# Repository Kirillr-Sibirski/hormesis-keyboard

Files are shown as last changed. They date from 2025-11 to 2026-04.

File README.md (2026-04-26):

# Hormesis Keyboard

A custom low-profile wireless split mechanical keyboard, inspired by the Corne v3.

---

## Overview

| Spec | Detail |
|---|---|
| Keys | 50 (split 25/25) |
| Layout | 5×6 column stagger per half + 3-key thumb cluster |
| Profile | Low-profile |
| Wireless | Bluetooth 5.0, up to 5 device profiles |
| Controller | nice!nano v2 (nRF52840) |
| RGB | WS2812 underglow, 25 LEDs per half |

---

## Repository Structure

```
hardware/
├── kicad/          KiCAD PCB schematic and layout
├── footprints/     Ergogen custom footprints
├── output/         Generated outputs (gerbers, outlines, cases)
├── top_plate/      Top plate Ergogen design
├── firmware/       Pre-built .uf2 files ready to flash
└── config.yaml     Ergogen PCB config

boards/             ZMK shield definition (hormesis_left / hormesis_right)
config/             ZMK keymap and firmware config
zephyr/             ZMK module config
build.yaml          ZMK GitHub Actions build targets
.github/workflows/  Auto-build firmware on push
```

---

## Layout

```
  1   2   3   4   5                   6   7   8   9   0
TAB   Q   W   E   R   T       Y   U   I   O   P  ESC
CAP   A   S   D   F   G       H   J   K   L   ;  SFT
  Z   X   C   V   B                   N   M   ,   .   /
                CTL ALT GUI     SPC  FN BSP
```

### Fn Layer (hold FN)

```
 F1  F2  F3  F4  F5                  F6  F7  F8  F9 F10
  `   !   @   #   $   %       ^   &   *   (   )  DEL
  _   _   -   =   [   ]      LFT DWN  UP RGT   '  ENT
BTC BT0 BT1 BT2 BT3             BT4 RGB  H+  S+   \
            USB BLE TOG     BRI EFF BOT
```

`BTC` = clear BT, `BT0–4` = select profile, `RGB` = toggle underglow, `H+/S+` = hue/saturation, `BRI` = brightness, `EFF` = next effect, `BOT` = bootloader, `USB/BLE/TOG` = output source.

---

## Flashing Firmware

Pre-built `.uf2` files are in `hardware/firmware/`:

```
hardware/firmware/hormesis_left-nice_nano_v2.uf2
hardware/firmware/hormesis_right-nice_nano_v2.uf2
```

1. Double-tap the reset button on the nice!nano — it mounts as a USB drive (`NICENANO`).
2. Drag the matching `.uf2` file onto the drive.
3. Flash left first, then right.

---

## Customizing Keymaps

**Edit the keymap** in `config/hormesis.keymap`, push to GitHub, and the Actions workflow auto-builds new firmware. Download from the Actions tab.

**ZMK Studio (GUI, no recompile):** Add `CONFIG_ZMK_STUDIO=y` to `config/hormesis.conf`, rebuild, flash, then use [zmk.studio](https://zmk.studio) to remap keys live over USB or BLE.

---

## Bill of Materials

| Part | Qty |
|---|-----|
| nice!nano v2 | 2 |
| Low-profile MX switches | 50 |
| Low-profile keycaps | 50 |
| WS2812B LEDs | 50 (25 per half) |
| SOD-123 diodes | 50 |
| JST PH 2.0 battery connector | 2 |
| LiPo battery (301230 or similar) | 2 |
| Reset switch (3×6mm SPST) | 2 |

---

## PCB Fabrication

Gerbers are in `hardware/kicad/gerber/`. Recommended fab settings:

- Layers: 2
- Thickness: 1.6 mm
- Surface finish: HASL or ENIG
- Quantity: 5 (gives 2 full keyboards + spares)

---

## License

MIT

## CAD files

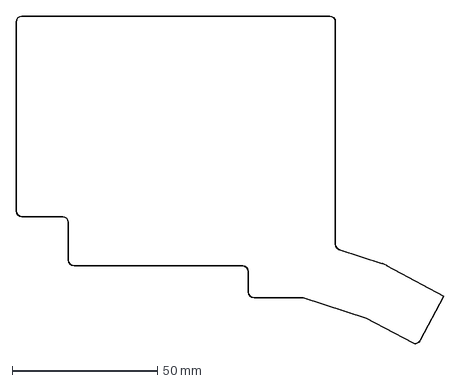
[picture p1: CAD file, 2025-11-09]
hardware/output/outlines/main.dxf
147.4 x 112.8 mm

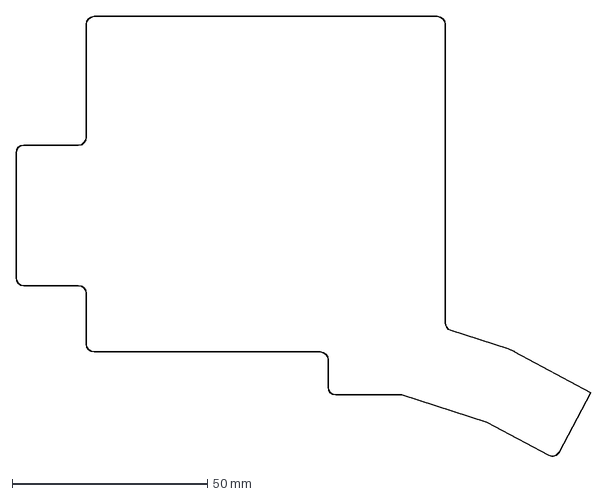
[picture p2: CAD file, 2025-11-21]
hardware/top_plate/output/outlines/main.dxf
147.4 x 112.8 mm

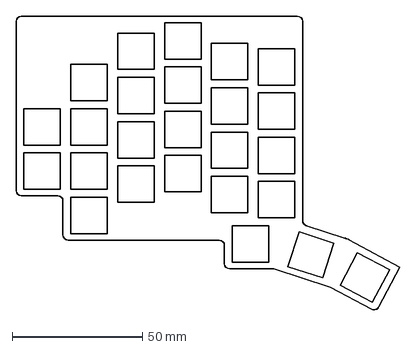
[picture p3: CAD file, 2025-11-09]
hardware/output/outlines/leftcutout.dxf
147.4 x 112.8 mm

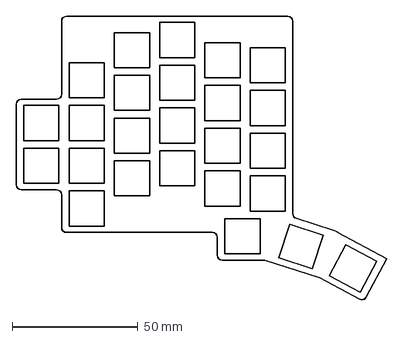
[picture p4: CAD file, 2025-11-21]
hardware/top_plate/output/outlines/leftcutout.dxf
147.4 x 112.8 mm

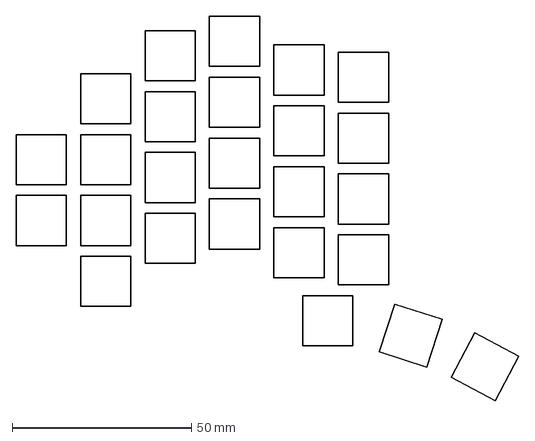
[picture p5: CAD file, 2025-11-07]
hardware/output/outlines/leftkeys.dxf
140.4 x 107.3 mm

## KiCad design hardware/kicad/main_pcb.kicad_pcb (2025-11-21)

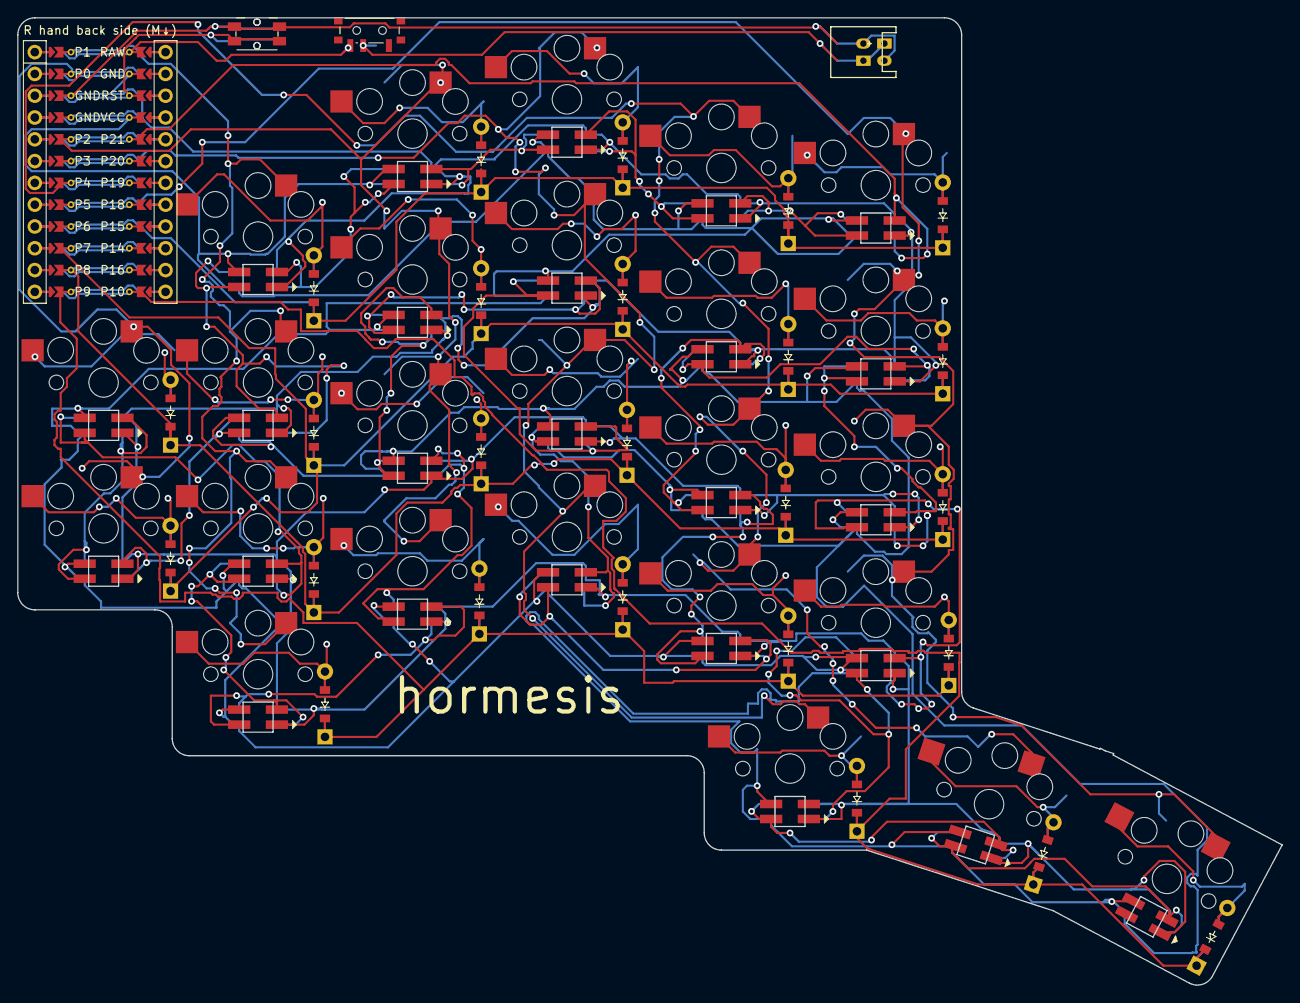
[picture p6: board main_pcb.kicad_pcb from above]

Board: 2 copper layers, 147.4 x 112.7 mm, 81 parts (0 on the bottom side), 66 nets.

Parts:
B1, B2: Panasonic_EVQPUL_EVQPUC
D1, D2, D3, D4, D5, D6, D7, D8, D9, D10, D11, D12, D13, D14, D15, D16, D17, D18, D19, D20, D21, D22, D23, D24, D25: ComboDiode
JST1, JST2: JST_PH_S2B-PH-K_02x2.00mm_Angled
LED1, LED2, LED3, LED4, LED5, LED6, LED7, LED8, LED9, LED10, LED11, LED12, LED13, LED14, LED15, LED16, LED17, LED18, LED19, LED20, LED21, LED22, LED23, LED24, LED25: WS2812B
MCU1: mcu_supermini_nrf52840
S1, S2, S3, S4, S5, S6, S7, S8, S9, S10, S11, S12, S13, S14, S15, S16, S17, S18, S19, S20, S21, S22, S23, S24, S25: PG1350
SW1: power_switch

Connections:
GND: B1.1, B2.1, JST1.2, JST2.2, LED1.3, LED2.3, LED3.3, LED4.3, LED5.3, LED6.3, LED7.3, LED8.3, LED9.3, LED10.3, LED11.3, LED12.3, LED13.3, LED14.3, LED15.3, LED16.3, LED17.3, LED18.3, LED19.3, LED20.3, LED21.3, LED22.3, LED23.3, LED24.3, LED25.3, MCU1.102, MCU1.121, MCU1.122
P0: MCU1.123, S21.1, S22.1
P1: MCU1.124, S1.1, S2.1, S3.1, S4.1
P2: MCU1.120, S5.1, S6.1, S7.1, S8.1
P3: MCU1.119, S9.1, S10.1, S11.1, S12.1, S23.1
P4: MCU1.118, S13.1, S14.1, S15.1, S16.1, S24.1
P5: MCU1.117, S17.1, S18.1, S19.1, S20.1, S25.1
P6: D4.1, D8.1, D12.1, D16.1, D20.1, MCU1.116
P7: D3.1, D7.1, D11.1, D15.1, D19.1, D21.1, MCU1.115
P8: D2.1, D6.1, D10.1, D14.1, D18.1, D22.1, MCU1.114
P9: D1.1, D5.1, D9.1, D13.1, D17.1, MCU1.113
P10: D23.1, D24.1, D25.1, MCU1.112
P21: LED20.4, MCU1.105
RAW: MCU1.101, SW1.3, SW1.6
RST: B1.2, B2.2, MCU1.103
VCC: LED1.1, LED2.1, LED3.1, LED4.1, LED5.1, LED6.1, LED7.1, LED8.1, LED9.1, LED10.1, LED11.1, LED12.1, LED13.1, LED14.1, LED15.1, LED16.1, LED17.1, LED18.1, LED19.1, LED20.1, LED21.1, LED22.1, LED23.1, LED24.1, LED25.1, MCU1.104
main_index_bottom: D13.2, S13.2
main_index_home: D14.2, S14.2
main_index_num: D16.2, S16.2
main_index_top: D15.2, S15.2
main_inner_bottom: D17.2, S17.2
main_inner_home: D18.2, S18.2
main_inner_num: D20.2, S20.2
main_inner_top: D19.2, S19.2
main_middle_bottom: D9.2, S9.2
main_middle_home: D10.2, S10.2
main_middle_num: D12.2, S12.2
main_middle_top: D11.2, S11.2
main_pinky_bottom: D1.2, S1.2
main_pinky_home: D2.2, S2.2
main_pinky_num: D4.2, S4.2
main_pinky_top: D3.2, S3.2
main_ring_bottom: D5.2, S5.2
main_ring_home: D6.2, S6.2
main_ring_num: D8.2, S8.2
main_ring_top: D7.2, S7.2
outer_outer_home: D22.2, S22.2
outer_outer_top: D21.2, S21.2
pos: JST1.1, JST2.1, SW1.2, SW1.5
rgb_main_index_bottom: LED9.2, LED13.4
rgb_main_index_home: LED13.2, LED14.4
rgb_main_index_num: LED16.4, LED20.2
rgb_main_index_top: LED14.2, LED15.4
rgb_main_inner_bottom: LED17.4, LED18.2
rgb_main_inner_home: LED18.4, LED19.2
rgb_main_inner_top: LED15.2, LED19.4
rgb_main_middle_bottom: LED9.4, LED10.2
rgb_main_middle_home: LED10.4, LED11.2
rgb_main_middle_num: LED12.4, LED16.2
rgb_main_middle_top: LED7.2, LED11.4
rgb_main_outer_home: LED21.2, LED22.4
rgb_main_outer_top: LED3.2, LED21.4
rgb_main_pinky_bottom: LED1.4, LED2.2
rgb_main_pinky_home: LED2.4, LED22.2
rgb_main_pinky_num: LED4.4, LED8.2
rgb_main_pinky_top: LED3.4, LED4.2
rgb_main_ring_bottom: LED1.2, LED5.4
rgb_main_ring_home: LED5.2, LED6.4
rgb_main_ring_num: LED8.4, LED12.2
rgb_main_ring_top: LED6.2, LED7.4
rgb_thumbfan_far: LED24.2, LED25.4
rgb_thumbfan_home: LED23.2, LED24.4
rgb_thumbfan_near: LED17.2, LED23.4
thumbfan_far_thumb: D25.2, S25.2
thumbfan_home_thumb: D24.2, S24.2
thumbfan_near_thumb: D23.2, S23.2

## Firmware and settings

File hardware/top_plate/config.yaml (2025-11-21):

units:
  px: cx + 2
  py: cy + 2

  pushX: (cx / 2)
  pushY: (cy / 2)

  padX: pushX + 2
  padY: pushY + 2

points:
  key.padding: cy
  zones:
    main:
      anchor:
        # Shift the PCB slightly to the right and down, otherwise it's weirdly positioned outside of the main sheet in KiCad
        shift: [100, -150]
      rows:
        bottom:
          # row_net: P9
        home:
          # row_net: P8
        top:
          # row_net: P7
        num:
          # row_net: P6
      columns:
        pinky:
          key:
            spread: cx
            bind: [16, 0, 0, 0]
            # column_net: P1
          rows:
            bottom:
              # led_in: "rgb_{{name}}"
              # led_out: rgb_main_ring_bottom
            home:
              # led_in: "rgb_{{name}}"
              # led_out: rgb_main_pinky_bottom
            top:
              # led_in: "rgb_{{name}}"
              # led_out: rgb_main_outer_top
            num:
              # led_in: "rgb_{{name}}"
              # led_out: rgb_main_pinky_top
        ring:
          key:
            stagger: 12
            spread: cx
            bind: [4, 0, 12, 0]
            # column_net: P2
          rows:
            bottom:
              # led_in: "rgb_{{name}}"
              # led_out: rgb_main_ring_home
            home:
              # led_in: "rgb_{{name}}"
              # led_out: rgb_main_ring_top
            top:
              # led_in: "rgb_{{name}}"
              # led_out: rgb_main_middle_top
            num:
              # led_in: "rgb_{{name}}"
              # led_out: rgb_main_pinky_num
        middle:
          key:
            stagger: 4
            spread: cx
            bind: [0, 0, 16, 0]
            # column_net: P3
          rows:
            bottom:
              # led_in: "rgb_{{name}}"
              # led_out: rgb_main_index_bottom
            home:
              # led_in: "rgb_{{name}}"
              # led_out: rgb_main_middle_bottom
            top:
              # led_in: "rgb_{{name}}"
              # led_out: rgb_main_middle_home
            num:
              # led_in: "rgb_{{name}}"
              # led_out: rgb_main_ring_num
        index:
          key:
            stagger: -8
            spread: cx
            bind: [8, 0, 8, 0]
            # column_net: P4
          rows:
            bottom:
              # led_in: "rgb_{{name}}"
              # led_out: rgb_main_index_home
            home:
              # led_in: "rgb_{{name}}"
              # led_out: rgb_main_index_top
            top:
              # led_in: "rgb_{{name}}"
              # led_out: rgb_main_inner_top
            num:
              # led_in: "rgb_{{name}}"
              # led_out: rgb_main_middle_num
        inner:
          key:
            stagger: -2
            spread: cx
            bind: [10, 0, 0, 0]
            # column_net: P5
          rows:
            bottom:
              # led_in: "rgb_{{name}}"
              # led_out: rgb_thumbfan_near
            home:
              # led_in: "rgb_{{name}}"
              # led_out: rgb_main_inner_bottom
            top:
              # led_in: "rgb_{{name}}"
              # led_out: rgb_main_inner_home
            num:
              # led_in: P21
              # led_out: rgb_main_index_num
    outer:
      anchor:
        ref: main_pinky_home
        shift: [-18, 0]
      columns:
        outer:
          key:
            spread: cx
            bind: [0, 0, 0, 0]
            # column_net: P0
      rows:
        top:
          # row_net: P7
          # led_in: "rgb_{{name}}"
          # led_out: rgb_main_outer_home
        home:
          # row_net: P8
          # led_in: "rgb_{{name}}"
          # led_out: rgb_main_pinky_home
    thumbfan:
      anchor:
        ref: main_inner_bottom
        shift: [-10, -17]
      columns:
        near:
          key:
            bind: [0, 3, 0, 0]
            # column_net: P3
            # led_in: "rgb_{{name}}"
            # led_out: rgb_thumbfan_home
        home:
          key:
            spread: 21
            splay: -18
            origin: [-12, -9]
            bind: [0.6, 2, 0, 4]
            # column_net: P4
            # led_in: "rgb_{{name}}"
            # led_out: rgb_thumbfan_far
        far:
          key:
            spread: 21
            splay: -10
            origin: [-10, -9]
            bind: [0.3, 0, 0, 4]
            # column_net: P5
            # led_in: "rgb_{{name}}"
            # no led_out
      rows:
        thumb:
          # row_net: P10
outlines:
  main:
    - where: true
      bound: true
      what: rectangle
      size: [cx + 2, cy + 2]
      fillet: 2
  leftkeys:
    - where: true
      what: rectangle
      size: [14, 14]
  leftcutout:
    - name: main
    - operation: subtract
      name: leftkeys

pcbs:
  main_pcb:
    outlines:
      main:
        outline: main
cases:
  plate:
    - name: leftcutout
      extrude: 1.2

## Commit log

2025-11-01 Add the basics, no adjustments yet
    [leftcutout.dxf, leftkeys.dxf, main.dxf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]
2025-11-05 Reverse keyswitches, reversible promicro
    [leftcutout.dxf, leftkeys.dxf, main.dxf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]
2025-11-07 Positions determined (more or less)
    [leftcutout.dxf, leftkeys.dxf, main.dxf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]
2025-11-09 Remove mounting holes & prepare ergogen for routing
    [leftcutout.dxf, main.dxf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]
2025-11-09 Adjust positions
    [main_pcb.kicad_pcb]
2025-11-21 PCB fully routed
    [kicad.kicad_pcb, kicad.kicad_sch, main_pcb.kicad_pcb]
2025-11-21 Add top plate
    [kicad.kicad_sch, leftcutout.dxf, leftkeys.dxf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]
2026-04-26 Combine into monorepo: add ZMK firmware config alongside hardware files
    Hardware files moved to hardware/, ZMK config (boards/, config/, build.yaml,
    .github/workflows/) added at repo root for GitHub Actions compatibility.
    Pre-built firmware .uf2 files included in hardware/firmware/.
    [kicad.kicad_pcb, leftcutout.dxf, leftkeys.dxf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]
2026-04-26 Update ZMK to main branch for ZMK Studio support
    v0.3 predates ZMK Studio — switching to main to get current firmware.
2026-04-26 Fix ZMK Studio build: workflow @main, snippet, cmake-args on left only
    - Workflow ref updated from @v0.3 to @main to match ZMK main branch
    - studio-rpc-usb-uart snippet and CONFIG_ZMK_STUDIO=y applied to left half only
    - Removed CONFIG_ZMK_STUDIO from hormesis.conf (must not apply to right half)
2026-04-26 Fix board name: nice_nano_v2 -> nice_nano/v2 for Zephyr 4.1 compat
2026-04-26 Fix board name: use nice_nano//zmk for ZMK main (Zephyr 4.1)
2026-04-26 Fix shield discovery: rename Kconfig files (capital K) and board overlays for Zephyr 4.1
2026-04-26 Remove undefined WS2812_STRIP symbol; ZMK_RGB_UNDERGLOW auto-selects LED_STRIP
